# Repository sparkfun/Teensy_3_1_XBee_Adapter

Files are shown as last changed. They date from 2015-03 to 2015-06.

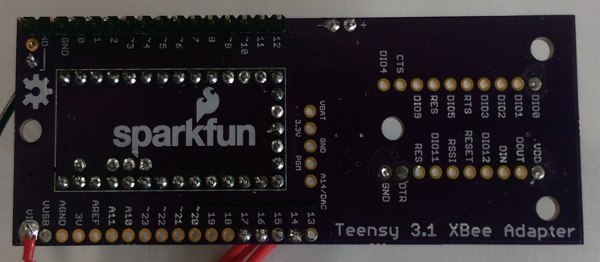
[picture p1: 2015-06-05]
Documentation/Bottom_board.jpg

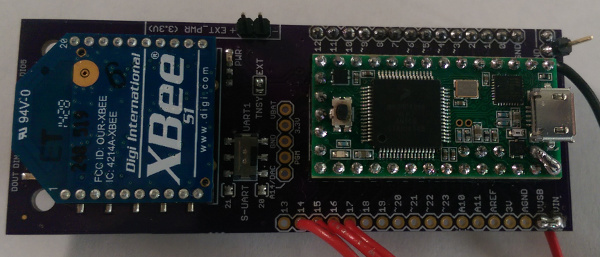
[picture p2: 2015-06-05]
Documentation/top_board.jpg

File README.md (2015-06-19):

SparkFun Teensy 3.1 XBee Adapter
=================================

SparkFun Teensy 3.1 XBee Adapter

[*SparkFun Teensy 3.1 XBee Adapter (BOB-13311)*](https://www.sparkfun.com/products/13311)

Adapter board from the Teensy3.1 to XBee radio modules.

Repository Contents
-------------------

* **/Documentation** - Datasheets, tutorial images. 
* **/Firmware** - Example code 
* **/Hardware** - Eagle design files (.brd, .sch)
* **/Production** - Production panel files (.brd)

Documentation
--------------
* **[Hookup Guide](https://learn.sparkfun.com/tutorials/teensy-xbee-adapter-hookup-guide)** - Basic hookup guide for the Teensy XBee Adapter.

License Information
-------------------
This product is _**open source**_! 

The **hardware** is released under [Creative Commons ShareAlike 4.0 International](https://creativecommons.org/licenses/by-sa/4.0/).
The firmware is released under the [MIT License](http://opensource.org/licenses/MIT). 

Please use, reuse, and modify these files as you see fit. Please maintain attribution to SparkFun Electronics and release anything derivative under the same license.

Distributed as-is; no warranty is given.

- Your friends at SparkFun.

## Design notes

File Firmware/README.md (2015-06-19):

SparkFun Teensy XBee Adapter Firmware
===================================

* **Examples** - Arduino examples

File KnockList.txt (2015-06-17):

Teensy 3.1 Xbee adapter knock list
	Mark (DONE) 

Identify Similar product repo (no lib, multiple examples)
	(DONE) -- User codebender for display and include github

Polish Examples folder
    (DONE)
	
Finish HookUp Guide text
	(Hookup guide link:
	https://learn.sparkfun.com/tutorials/teensy-xbee-adapter-hookup-guide)
	
	(DONE)Fix LED pins (should be f4-11)
	
Photograph with Juan
	(DONE)
	
Push to marcom

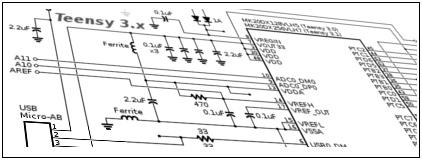
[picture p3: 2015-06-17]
Documentation/TeensySchematic.jpg

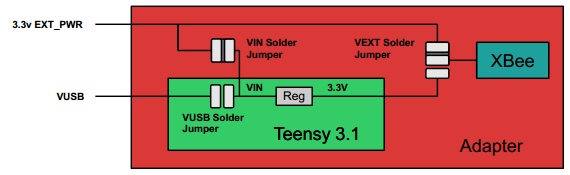
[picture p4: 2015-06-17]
Documentation/PowerOption2.png

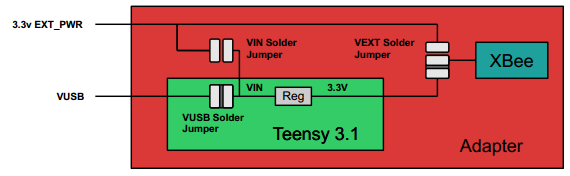
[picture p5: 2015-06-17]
Documentation/PowerOption1.png

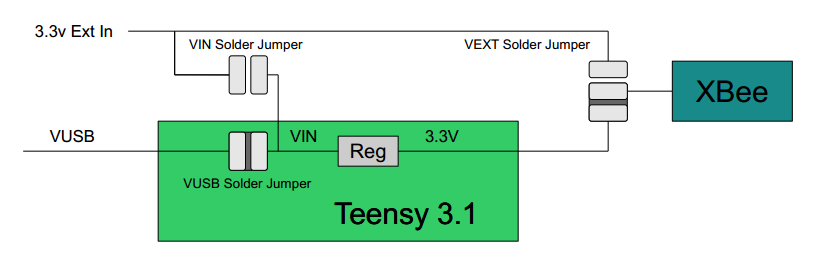
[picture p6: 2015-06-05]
Documentation/PO1.png

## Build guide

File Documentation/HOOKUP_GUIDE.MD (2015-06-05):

# Getting Started With The XBee And Teensy 3.1

## Introduction
When microcontroller power in a tight space is required, the Teensy 3.1/LC is a good place to get it.  When a decently ranged no-frills serial link is required, the XBee is the go-to.  The Teensy to XBee adapter board joins the two with easy, but how easy is it?  This tutorial will demonstrate the basics of using the adapter board.

This tutorial demonstrates:
* How to initialize Teensy 3.1/LC HW serial
* How to initialize Teensy 3.1 SW serial using softwareSerialAlt library
* The basics of packetizing data.
* How to make a simple controller that effects something far away
* How to build a wireless game controller for a computer.

### Materials Used

You will need a few components and tools to follow along with this tutorial. Here is what you will need:

-----------------------------------WISHLIST GOES HERE-----------------------------------

If you do not have specifically a 3.3V Arduino Pro, there are a number of ways to complete the walkthrough. In general, you will need:

* **Arduino or other microcontroller** -- You will need something that is capable of I<sup>2</sup>C and communicating back to the computer (e.g. [serial communications](tutorials/8)). The microcontroller needs to have a **3.3V I/O voltage** or you will have to use a level shifter. We are using the [3.3V Arduino Pro](https://www.sparkfun.com/products/10914), but the [3.3V Arduino Pro Mini](https://www.sparkfun.com/products/11114) would work as well.
* **Teensy 3.1/LC** -- If you are using a 5V Arduino, like the [Uno](https://www.sparkfun.com/products/11021) or [RedBoard](https://www.sparkfun.com/products/12757), you will need to use a level shifter, such as the [bi-directional logic level converter](https://www.sparkfun.com/products/12009).
* **Connectors** -- You will need to interface your microcontroller with the breakout board. [Male headers](https://www.sparkfun.com/products/116) are perfect if you're using a [breadboard](https://www.sparkfun.com/products/11026). Another option is to use [wire](https://www.sparkfun.com/products/11375) to connect the breakout board directly to the microcontroller.
* **Soldering tools** -- After you've picked a connector, you will need to solder it to the breakout board. A [simple soldering iron](https://www.sparkfun.com/products/9507) and some [solder](https://www.sparkfun.com/products/9163) should be all you need.

### Recommended Reading

Before getting started, there are a few concepts that you should be familiar with. If you haven't used a Teensy or XBee before, read these tutorials before continuing:

* [Teensy Quickstart](http://www.pjrc.com/teensy/first_use.html) - External link to PJRC, first powering of a Teensy
* [Teensyduino Software](http://www.pjrc.com/teensy/teensyduino.html) - External link to PJRC, using the Teensy with Arduino software
* [Exploring XBees and XCTU](https://learn.sparkfun.com/tutorials/exploring-xbees-and-xctu) - Guide to configuring the XBees using the XBee tool XCTU
* [XBee Buying Guide](https://www.sparkfun.com/pages/xbee_guide) - Shows various XBee models including current consumption
use an Arduino to control the APDS-9960
* [Serial Terminal Basics](https://learn.sparkfun.com/tutorials/terminal-basics) - Lots of information about serial.  If you've only ever used the Arduino Serial monitor (or no terminal at all), this is a good resource.  It shows how to get serial terminals working on Mac, Linux, and Windows.

### Tools or materials required

* Soldering iron and flux core solder
* Spare wire
* X-acto or knife for cutting traces (possibly)
* Breadboard

### Software required
* Arduino IDE
* Teensyduino add-on
* AltSoftSerial library
* X-CTU

## Hardware Overview
Look at this picture!  *look at it...*

## Assembly
The basic methodology for developing with the Teensy and XBee goes like this:
* Determine how to power
* Connect the hardware
* Configure the XBees
* Establish serial over XBee (test all systems)
* Build and test the actual project

### Determine how the system is going to be powered
The XBee requires around 3.3v to operate depending on model.  The Teensy has an on-board regulator that outputs 3.3v which is perfect, but only for lower power radios.

Photo

*Powering from the Teensy's internal regulator*

This is the default configuration.  The internal regulator can supply about 100mA of current for 3.3v use, including what is consumed by the Teensy and things on the 3.3v rail. XBees up to 2mW (non-"pro" models) consume up to 40mA, so if you have a basic XBee this is probably the route for you.  Supply 3.7 to 5.5v (or USB power) and you're good to go.

Photo

*Powering the XBee from an external 3.3v regulator*

If you have a higher powered XBee, or more than 100mA of load on your 3.3v rail, you'll need to disconnect the XBee from the internal regulator and supply 3.3v from somewhere else.  A [Breadboard Power Supply Stick](https://www.sparkfun.com/products/13157) is a possible power source for this application.

In this case, switch the TNSY-EXT jumper to EXT, short the VIN-EXT_PWR jumper, and cut the trace between the Teensy's USB PWR jumper.  Now both the Teensy and XBee are powered from the ext power pins, so you'll need to provide power and plug in the USB if you want to reprogramming the device.

### Now that powering has been figured out, it's time to connect the teensy to the XBee.
The XBee sockets straight into the adapter.  It's good to go!
Neither the Teensy nor the adapter has have headers.  Here are some options for connecting the two.
* Solder headers into the teensy, and pins into the adapter (or visa-versa) - This is a good option because the two are easily seperable.  Note: the pair are quite thick in this configuration and the headers are difficult to remove.  If you *know* you'll be moving to an alternate connection scheme, it may be a good idea to test things with short flexible wires before locking things down.
* Solder short lengths of wire between the pins you wish to connect - this is a good idea if you know you'll be moving to some more permenent solution.  Also, only solder wires where you need, such as power, ground, TX, RX, and miscelanious GPIO.
* Solder the two boards directly together without pins or wires at all - This is an advanced technique but results in a very thin board stack.  Don't do this until you are 100% confidant in your design!  Verify first, then solder together.  Seperating the boards afterwards can destroy them.

### Connect Periphery Equipment
Use the outer holes to connect all manor of switches and sensors that you wish to read from the Teensy.  This tutorial makes a controller, so buttons and knobs are connected as shown in this diagram.

*Fritzing diagram showing wiring of the buttons for this example*

### Configure the XBees
The XBees are shipped with a default configuration (see XBee documentation).  Even if they work out of the box, you'll be using the default IDs and will be suseptable to unseen XBees interfering with your system (because some other designer had the similar thought, "I'm the only one here, why not use the default IDs.") Also, you can change other more advanced features once you're familiar with the concepts.

**The parameters used for this demo**
* ID/PAN ID = A5F1 - This can be any 16 bit hex value used to identify your network.  Make sure it is the same for both radios and unique in your area.  A5F1 was randomly chosen for this guide.  You can choose any ID for your network.
* Data rate = 9600
* Parity = N
* All others at factory default

**Configuring XBees with USB based explorers**

* Socket an XBee into the explorer matching the silkscreen orientation
* Plug the explorer into the USB port
* Open X-CTU
* Select your explorer's serial port
* Querry the XBee to make sure the drivers are working
* Read the configuration from the XBee
* Modify the parameters
* Write the new configuration to the XBee

Repeat this process so that both XBees have the new configuration.

### Power the System!
Apply (HOW MUCH VOLTAG?) to the system.  Does the (WHAT TURNS ON?)  Try running the blink sketch to determine if the Teensy is really powered and ready to recieve firmware.

## Firmware
### Theory
### Working with your serial ports
Difficulties arise while working with wireless devices because more than one serial port is in use.  Where Arduino allows you to simply load the serial monitor to talk to your code, be extra careful remembering which ports what device and which terminal are using.

For this example the computer is one party in the communication by using the XBee explorer.  Get this port open and communicating to the XBee explorer, then leave it alone.  It ushers bytes you type into it into the air, and prints whatever comes into it's antenna to your screen.  When the system is fully functional, this terminal will tell you what buttons are being pressed.

The Arduino serial monitor connects to the target over the USB cable.  This serial link isn't going to the XBee and won't be connected to anything when the controller is fully mobile, so may not have much use but it's important to remember that it exists, and to not confuse it with the other serial ports.  Actually, it can be usefull to get debugging information from your program while working with it.

The trickest serial link in this project is the one that goes from the Teensy to the XBee because we have little information about it.  If you have access to an oscilliscope the link can be probed, but in lieu of that all we get is a little blinking light we become thankful for.

### Test your serial and XBee configuration
*Two sketches are provided to ease bringing the XBees online.  They pass data between the XBee and the serial monitor using the HW UART or the SW UART 'AltSoftSerial'*

**teensy_3_1_xbee_UART1_example**

Set the adapter's serial switch to UART1.  Then, load and run the example.  Open the serial monitor.  Text entered in the serial monitor will be passed to the XBee, and come out the X-CTU (or other, I use Tera Term) serial monitor.  Typing in that terminal will send the text back to the Arduino serial monitor.  This tests the HW UART and XBee configurations

**teensy_3_1_xbee_SUART_example**

This sketch works much like the UART1 example but with the AltSoftSerial library, leaving the HW UART free to connect to other resources.  Set the adapter's switch to UART1 and run the sketch.  Text should be passed between the two serial terminals.

### Running the demo sketches

**teensy_3_1_xbee_buttons_and_leds_example**

This sketch demonstrates bi-directional communication and shows off operation that is more than just data echo.

**Connections**

* Attach buttons to pins 14-17 of the Teensy, and to ground.  The pins are pulled up inside the teensy and will float high until a button is depressed.
* Attach LEDs from pins 14-21 of the Teensy, through a current limiting resistor, to ground.  It's not so important to have all 8, 2 or 3 is enough to demonstrate the effect.

**Each time the loop() runs, the sketch**

* Converts button presses to an ascii repersentation
* Prints the button states to the Arduino serial monitor
* Transmits the button states as a series of ascii characters
* Checks for received data from the XBee.  If a number 1-8 is received, the associated LED on pins 14-21 is illuminated.  If any other character is received, all 8 LEDs are are switched off.

**teensy_3_1_xbee_gamepad_controller**

This sketch is used to create a NES style 8 button controller with D-pad, A, B, Start and Select.  It works similarly to the previous example in that it builds a packet of ascii characters that depict the state of the button and transmits them out the XBee.  It has an upgraded.  It's different in that the LED feedback and Arduino serial manager code has been removed, and button state information is now tracked.  This sketch checks the button states as fast as possible, and only sends an ascii packet out the XBee if the state of the buttons has changed.  This allows the XBee to not consume superflurious power if the controller is on battery power.

**Connections**

* Pin 2: Start button
* Pin 3: Select button
* Pin 4: B button
* Pin 5: A button
* Pin 6: Up button
* Pin 7: Down button
* Pin 8: Left button
* Pin 9: Right button
* Set switch to UART1

**teensy_3_1_xbee_gamepad_receiver**

This sketch causes the Teensy to behave like a USB keyboard.  It parses the data from the XBee and 'presses a key' in corrispondence with what key is being depressed on the controller.  When a controller button is pressed and held, the teensy acts like a keyboard with a key held down.  This allows the teensy to interface to a ROM emulator or game that has map-able keyboard input.

**Configuration**

* Set switch to UART1
* In the Arduino IDE, Select Tools -> USB type: -> Keyboard + Mouse + Joystick

After the sketch uploads your computer may have to go through a new device like detection.  When it is done, open a text editor and use the controller to send some XBee data to the receiver.  If everything is correct, numbers should be typed into the text editor.

This sketch was tested on windows 7 and mac OS 10.10.

## Conclusion

## Resources and Going Further

Going Further/Further Reading

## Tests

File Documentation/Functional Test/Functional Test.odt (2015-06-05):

# Functional Test

## Hardware uart test

### Method

Run the Hardware Uart test from the github repository

Use Teensy 3.1 and Teensy LC

### Results

Sketch runs and passes data on Teensy 3.1

Sketch runs and passes data on Teensy LC

Switch label is correct.

## Software uart test

### Method

Run the Software UART test from the github repository

Use Teensy 3.1 and Teensy LC

### Results

Sketch runs and passes data on 3.1.

Switch label is correct.

Teensy LC does not work- perhaps AltSoftwareSerial needs to be updated

## Low power configuration


### Method

1. M ake the jumper configuration as shown.
2. Attach to computer USB port.
3. Replace the XBee with a series of loads 0mA to 500mA
4. Measure VIN on the Teensy, regulated 3.3v rail, and current load applied

### Results

The internal regulator starts cutting out above 200mA and the voltage quickly drops. Damage not apparent.

## High power configuration

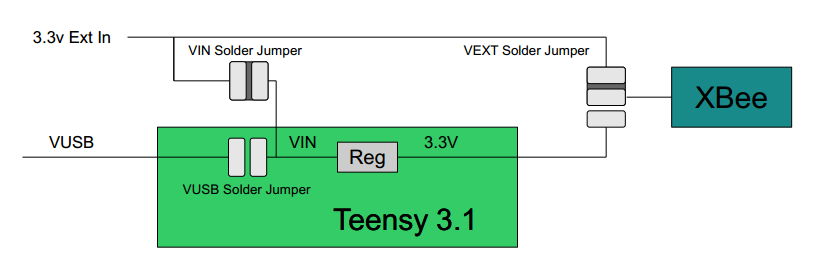
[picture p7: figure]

### Method

1. M ake the jumper configuration as shown.
2. Attack to 3.3v stable regulated supply.
3. Replace the XBee with a series of loads 0mA to 500mA
4. Measure VIN on the Teensy, regulated 3.3v rail, and current load applied

### Results

The connection is direct, so the slight current/voltage relationship is due to the source and wire impedance. Notice that at this level, there is no 5v rail.

## LED colors and operations

### Method

1. Run the HW UART code. This will test will test DIO5, DOUT and DIN. Send data from the USB dongle to the Teensy via airwaves to test the signal strength LED.
2. Do the colors match other XBee products?

Function | Arduino shield | USB dongle
RSSI | Green | Green
Air to MCU | "DOUT", Red | "TX", Red
MCU to Air | "DIN", Green | "RX", Green
DIO5 | Green | Not Present
PWR | Red | Red

3. Are you blinded by the lights?

### Results

Function | Silk/Color | Correct? | Brightness OK?
RSSI | Green | Yes | Yes
Air to Teensy | "DIN", Red | Color correct, lable not | Yes
Teensy to Air | "DOUT", Green | Color correct, lable not | Yes
DIO5 | Green | Yes | Yes
PWR | Red | Yes | Yes

## Action items/Corrections

1. Twist power LEDs to match other LEDs.
2. Mark PWR to LED and jumper pads.
3. Swap DIN and DOUT lables.
4. Add top flame
5. Remove AGND DGND jumper
6. Fix dimention lines- make them go all the way to the holes
7. Do something about Teensy LC and software serial?
8. Update revision number

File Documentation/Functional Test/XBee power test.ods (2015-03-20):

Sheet: Low Power
Load I (amps) | Vin (volts) | 3.3v(volts) | Resistor calcs
0.000 | 4.980 | 3.260 | Voltage | Amperage | Ohms | Real resistor | Amperage
0.055 | 4.880 | 3.240 | 3.3 | 0.05 | 66 | 60 | 0.06
0.081 | 4.830 | 3.240 | 3.3 | 0.1 | 33 | 40 | 0.08
0.109 | 4.780 | 3.230 | 3.3 | 0.15 | 22 | 30 | 0.11
0.214 | 4.590 | 3.210 | 3.3 | 0.2 | 16.5 | 14.7 | 0.22
0.233 | 4.550 | 2.330 | 3.3 | 0.25 | 13.2 | 10 | 0.33
0.234 | 4.550 | 2.110 | 3.3 | 0.3 | 11 | 9 | 0.37
0.238 | 4.550 | 1.780 | 3.3 | 0.35 | 9.43 | 6.5 | 0.51
 |  |  | 3.3 | 0.4 | 8.25
 |  |  | 3.3 | 0.45 | 7.33
 |  |  | 3.3 | 0.5 | 6.6
 |  |  | 3.3 | 0.55 | 6
 |  |  | 3.3 | 0.6 | 5.5
 |  |  | 3.3 | 0.65 | 5.08
 |  |  | 3.3 | 0.7 | 4.71
 |  |  | 3.3 | 0.75 | 4.4
 |  |  | 3.3 | 0.8 | 4.13
 |  |  | 3.3 | 0.85 | 3.88
 |  |  | 3.3 | 0.9 | 3.67
 |  |  | 3.3 | 0.95 | 3.47
 |  |  | 3.3 | 1 | 3.3

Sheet: Sheet2
Load I (amps) | (same) | 3.3v(volts)
0.000 |  | 3.310
0.056 |  | 3.300
0.083 |  | 3.295
0.110 |  | 3.285
0.217 |  | 3.256
0.330 |  | 3.225
0.354 |  | 3.218
0.417 |  | 3.201
0.512 |  | 3.174

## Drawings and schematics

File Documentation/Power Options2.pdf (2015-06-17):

# XBee

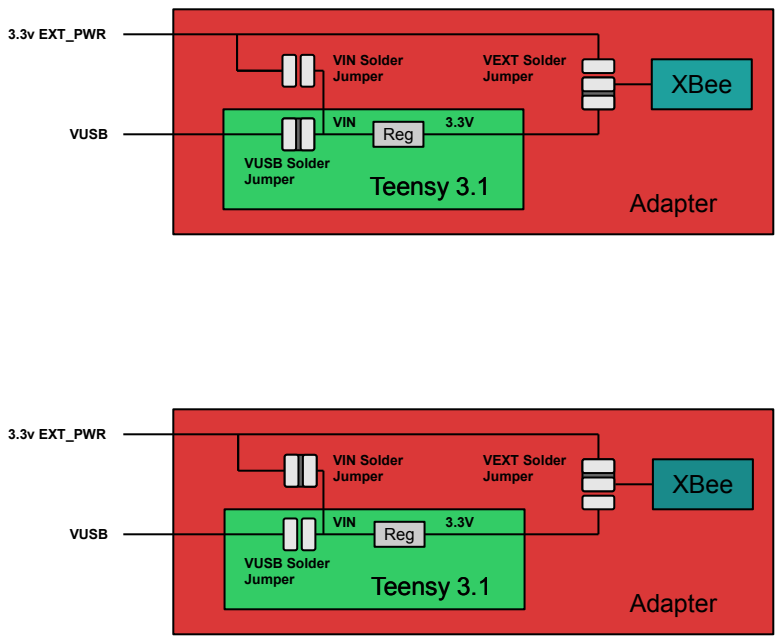
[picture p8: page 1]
Reg; VIN; VUSB; Teensy 3.1; 3.3v EXT_PWR; VUSB Solder Jumper; VIN Solder Jumper; VEXT Solder Jumper; XBee; Adapter

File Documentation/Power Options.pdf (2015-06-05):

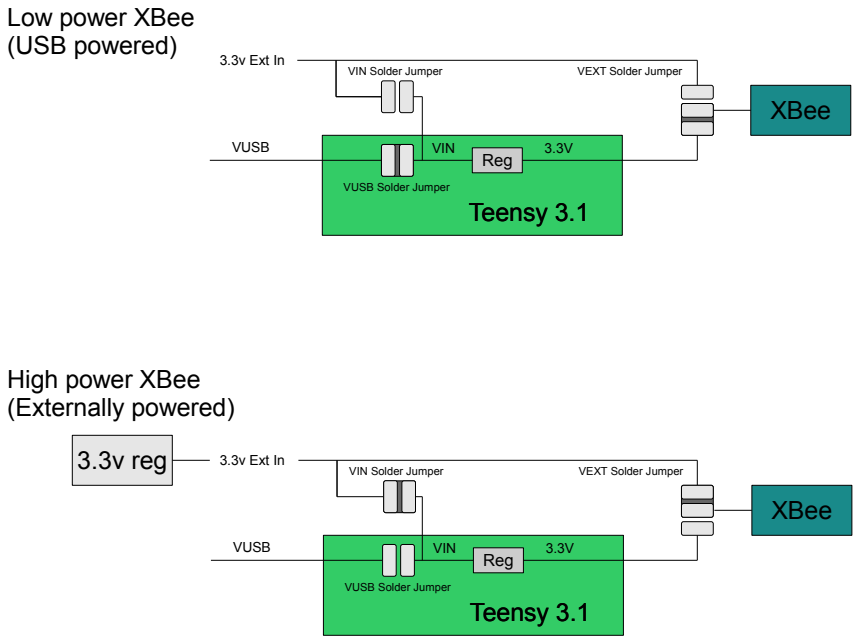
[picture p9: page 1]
XBee; Reg; VUSB; VIN; 3.3v reg; Teensy 3.1; 3.3v Ext In; VIN Solder Jumper; VEXT Solder Jumper

Low power XBee
(USB powered)

VUSB Solder Jumper

High power XBee
(Externally powered)

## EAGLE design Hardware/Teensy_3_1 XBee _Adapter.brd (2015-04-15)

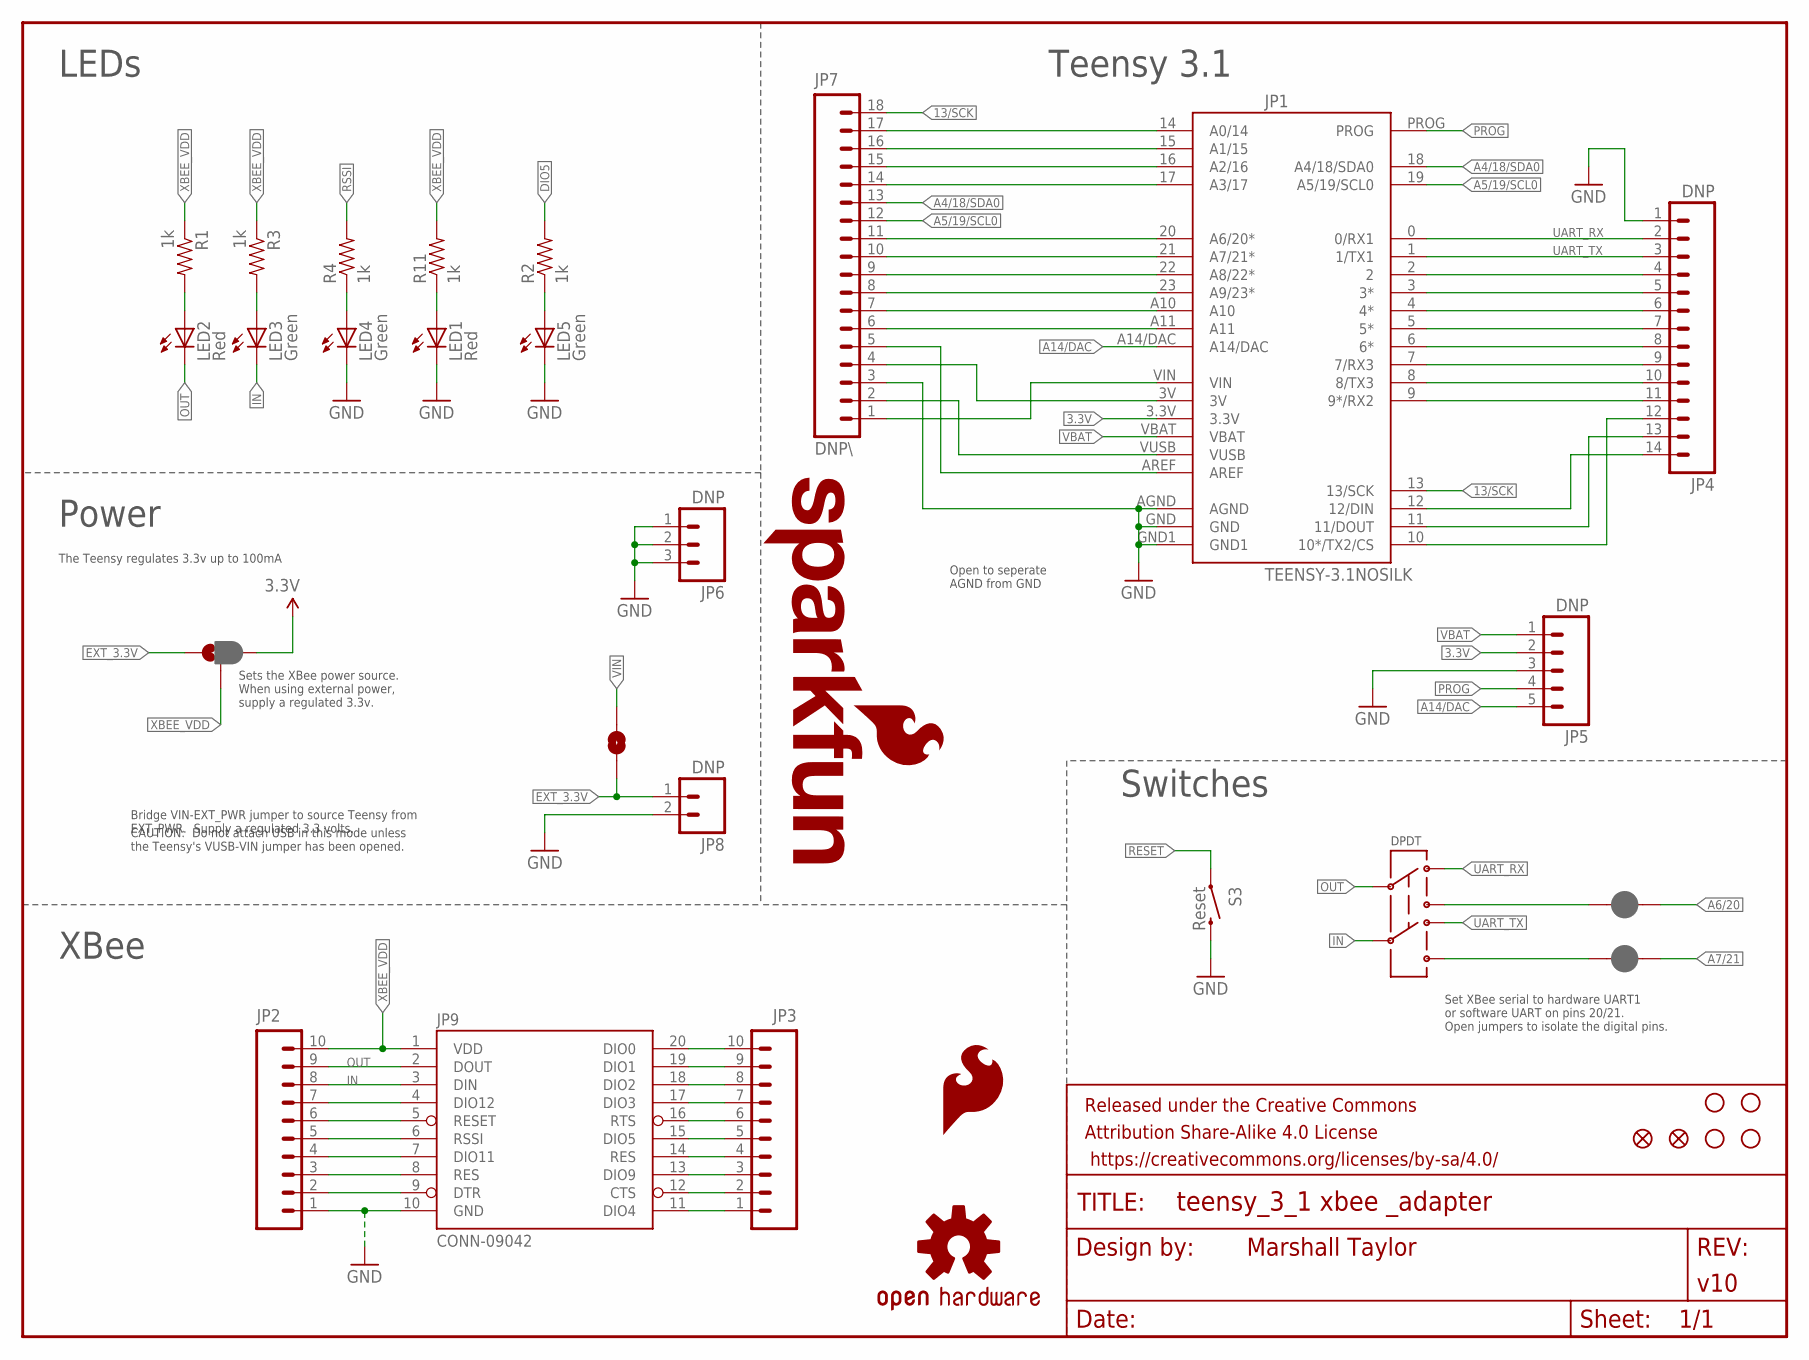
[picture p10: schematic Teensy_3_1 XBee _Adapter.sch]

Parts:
FID1, FID2: FIDUCIAL1X2; FIDUCIAL-1X2
FRAME1: FRAME-LETTER; CREATIVE_COMMONS
JP1: TEENSY-3.1NOSILK; TEENSY-3.1_NOSILK
JP2, JP3: M10NO_SILK_PTH_FEMALE; 1X10_NO_SILK
JP4: DNP; 1X14
JP5: DNP; 1X05
JP6: DNP; 1X03
JP7: DNP\; 1X18
JP8: DNP; 1X02
JP9: CONN-09042; XBEE-SMD
LED1, LED2: Red; LED-0603
LED3, LED4, LED5: Green; LED-0603
LOGO1: SFE_LOGO_FLAME.2_INCH; SFE_LOGO_FLAME_.2
LOGO2: OSHW-LOGOM; OSHW-LOGO-M
LOGO3: SFE_LOGO_NAME_FLAME.2_INCH; SFE_LOGO_NAME_FLAME_.2
R1, R2, R3, R4, R11: 1k; 0603-RES
S2: DPDT; AYZ0202
S3: Reset; TACTILE-SWITCH-SMD
SJ1: D_TX; PAD-JUMPER-2-NC_BY_PASTE_YES_SILK
SJ3: D_RX; PAD-JUMPER-2-NC_BY_PASTE_YES_SILK
SJ4: JUMPER-PAD-3-2OF3_NC_BY_PASTE; PAD-JUMPER-3-2OF3_NC_BY_PASTE_YES_SILK_FULL_BOX
SJ5: EXT_JPR; PAD-JUMPER-2-NO_YES_SILK
STANDOFF1, STANDOFF2, STANDOFF3, STANDOFF4: STAND-OFF

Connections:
2: JP1.2, JP4.4
3: JP1.3 (3*), JP4.5
3.3V: JP1.3.3V, JP5.2, SJ4.3
3V: JP1.3V, JP7.4
4: JP1.4 (4*), JP4.6
5: JP1.5 (5*), JP4.7
6: JP1.6 (6*), JP4.8
7/RX3: JP1.7 (7/RX3), JP4.9
8/TX3: JP1.8 (8/TX3), JP4.10
9/RX2: JP1.9 (9*/RX2), JP4.11
10/TX2/CS: JP1.10 (10*/TX2/CS), JP4.12
11/DOUT: JP1.11 (11/DOUT), JP4.13
12/DIN: JP1.12 (12/DIN), JP4.14
13/SCK: JP1.13 (13/SCK), JP7.18
A0/14: JP1.14 (A0/14), JP7.17
A1/15: JP1.15 (A1/15), JP7.16
A2/16: JP1.16 (A2/16), JP7.15
A3/17: JP1.17 (A3/17), JP7.14
A4/18/SDA0: JP1.18 (A4/18/SDA0), JP7.13
A5/19/SCL0: JP1.19 (A5/19/SCL0), JP7.12
A6/20: JP1.20 (A6/20*), JP7.11, SJ3.1
A7/21: JP1.21 (A7/21*), JP7.10, SJ1.1
A8/22: JP1.22 (A8/22*), JP7.9
A9/23: JP1.23 (A9/23*), JP7.8
A10: JP1.A10, JP7.7
A11: JP1.A11, JP7.6
A14/DAC: JP1.A14/DAC, JP5.5
AREF: JP1.AREF, JP7.5
CTS: JP3.2, JP9.12 (CTS)
DIO0: JP3.10, JP9.20 (DIO0)
DIO1: JP3.9, JP9.19 (DIO1)
DIO2: JP3.8, JP9.18 (DIO2)
DIO3: JP3.7, JP9.17 (DIO3)
DIO4: JP3.1, JP9.11 (DIO4)
DIO5: JP3.5, JP9.15 (DIO5), R2.2
DIO9: JP3.3, JP9.13 (DIO9)
DIO11: JP2.4, JP9.7 (DIO11)
DIO12: JP2.7, JP9.4 (DIO12)
DTR: JP2.2, JP9.9 (DTR)
EXT_3.3V: JP8.1, SJ4.1, SJ5.2
GND: JP1.AGND, JP1.GND, JP1.GND1, JP2.1, JP4.1, JP5.3, JP6.1, JP6.2, JP6.3, JP7.3, JP8.2, JP9.10 (GND), LED1.C, LED4.C, LED5.C, S3.3 (2)
IN: JP2.8, JP9.3 (DIN), LED3.C, S2.5
unnamed: LED1.A, R11.1
unnamed: LED2.A, R1.2
unnamed: LED3.A, R3.2
unnamed: LED4.A, R4.1
unnamed: LED5.A, R2.1
unnamed: S2.6, SJ1.2
unnamed: S2.3, SJ3.2
OUT: JP2.9, JP9.2 (DOUT), LED2.C, S2.2
PROG: JP1.PROG, JP5.4
RES: JP2.3, JP9.8 (RES)
RES2: JP3.4, JP9.14 (RES)
RESET: JP2.6, JP9.5 (RESET), S3.1
RSSI: JP2.5, JP9.6 (RSSI), R4.2
RTS: JP3.6, JP9.16 (RTS)
UART_RX: JP1.0 (0/RX1), JP4.2, S2.1
UART_TX: JP1.1 (1/TX1), JP4.3, S2.4
VBAT: JP1.VBAT, JP5.1
VIN: JP1.VIN, JP7.1, SJ5.1
VUSB: JP1.VUSB, JP7.2
XBEE_VDD: JP2.10, JP9.1 (VDD), R1.1, R3.1, R11.2, SJ4.2

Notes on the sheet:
Switches
Teensy 3.1
XBee
Power
LEDs
The Teensy regulates 3.3v up to 100mA
Sets the XBee power source. When using external power, supply a regulated 3.3v.
Bridge VIN-EXT_PWR jumper to source Teensy from EXT_PWR. Supply a regulated 3.3 volts.
CAUTION: Do not attach USB in this mode unless the Teensy's VUSB-VIN jumper has been opened.
Set XBee serial to hardware UART1 or software UART on pins 20/21. Open jumpers to isolate the digital pins.
DPDT
Open to seperate AGND from GND

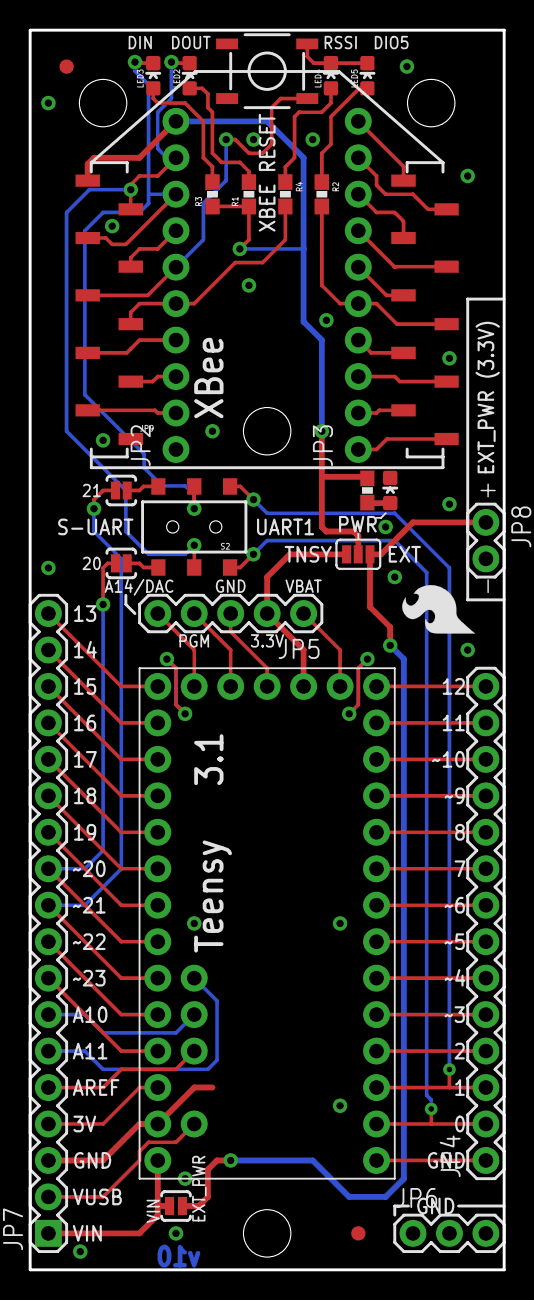
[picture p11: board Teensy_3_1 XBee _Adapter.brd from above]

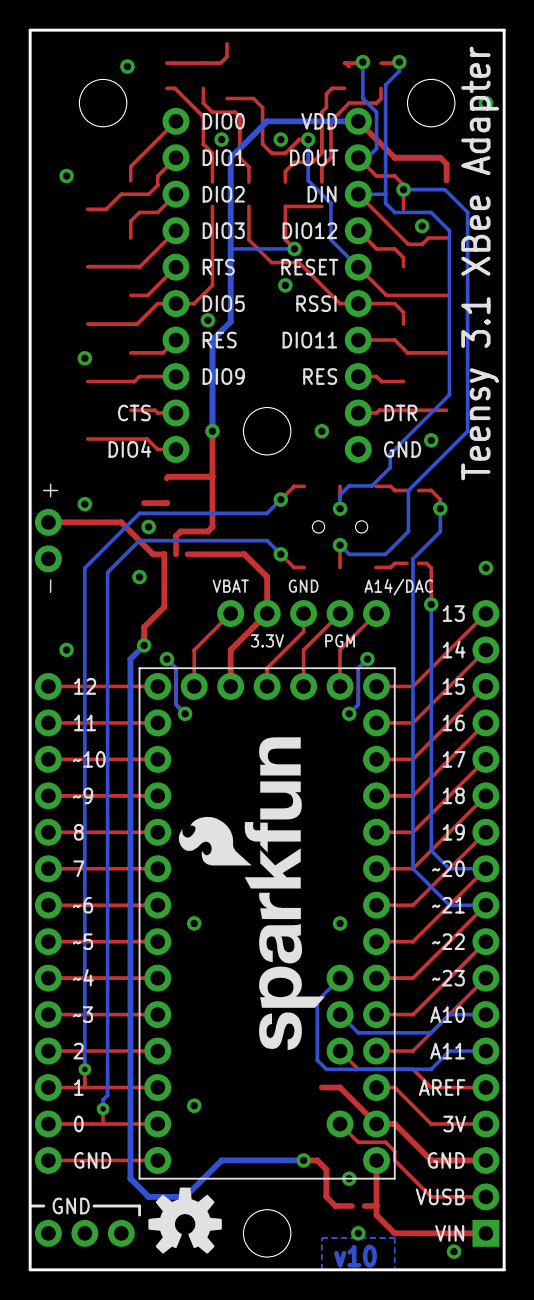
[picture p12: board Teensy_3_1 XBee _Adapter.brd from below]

Board: 2 copper layers, 33.0 x 86.4 mm, 35 parts (2 on the bottom side), 62 nets.

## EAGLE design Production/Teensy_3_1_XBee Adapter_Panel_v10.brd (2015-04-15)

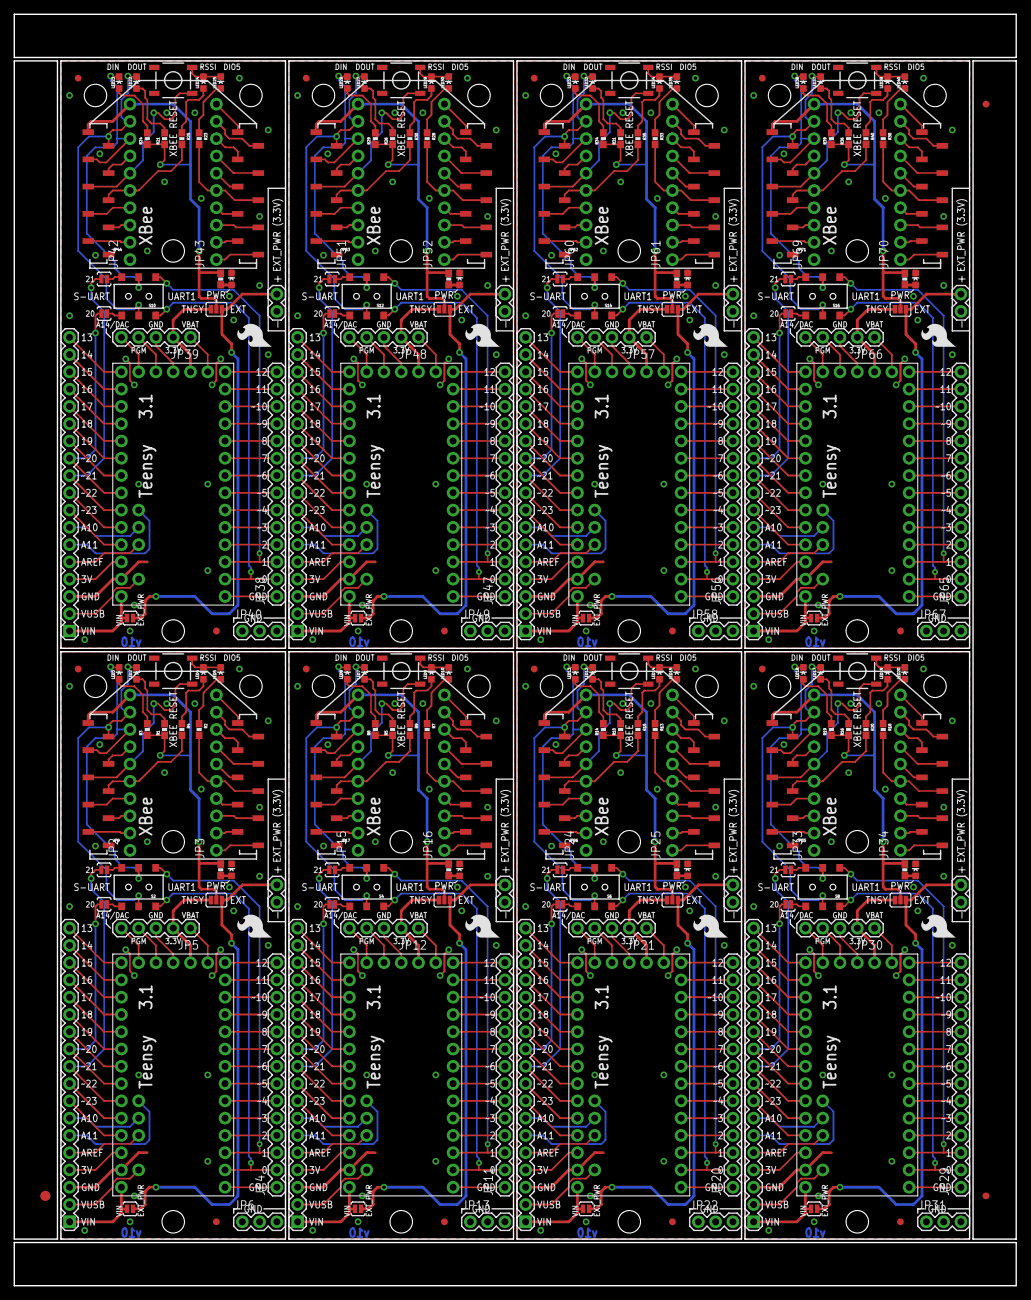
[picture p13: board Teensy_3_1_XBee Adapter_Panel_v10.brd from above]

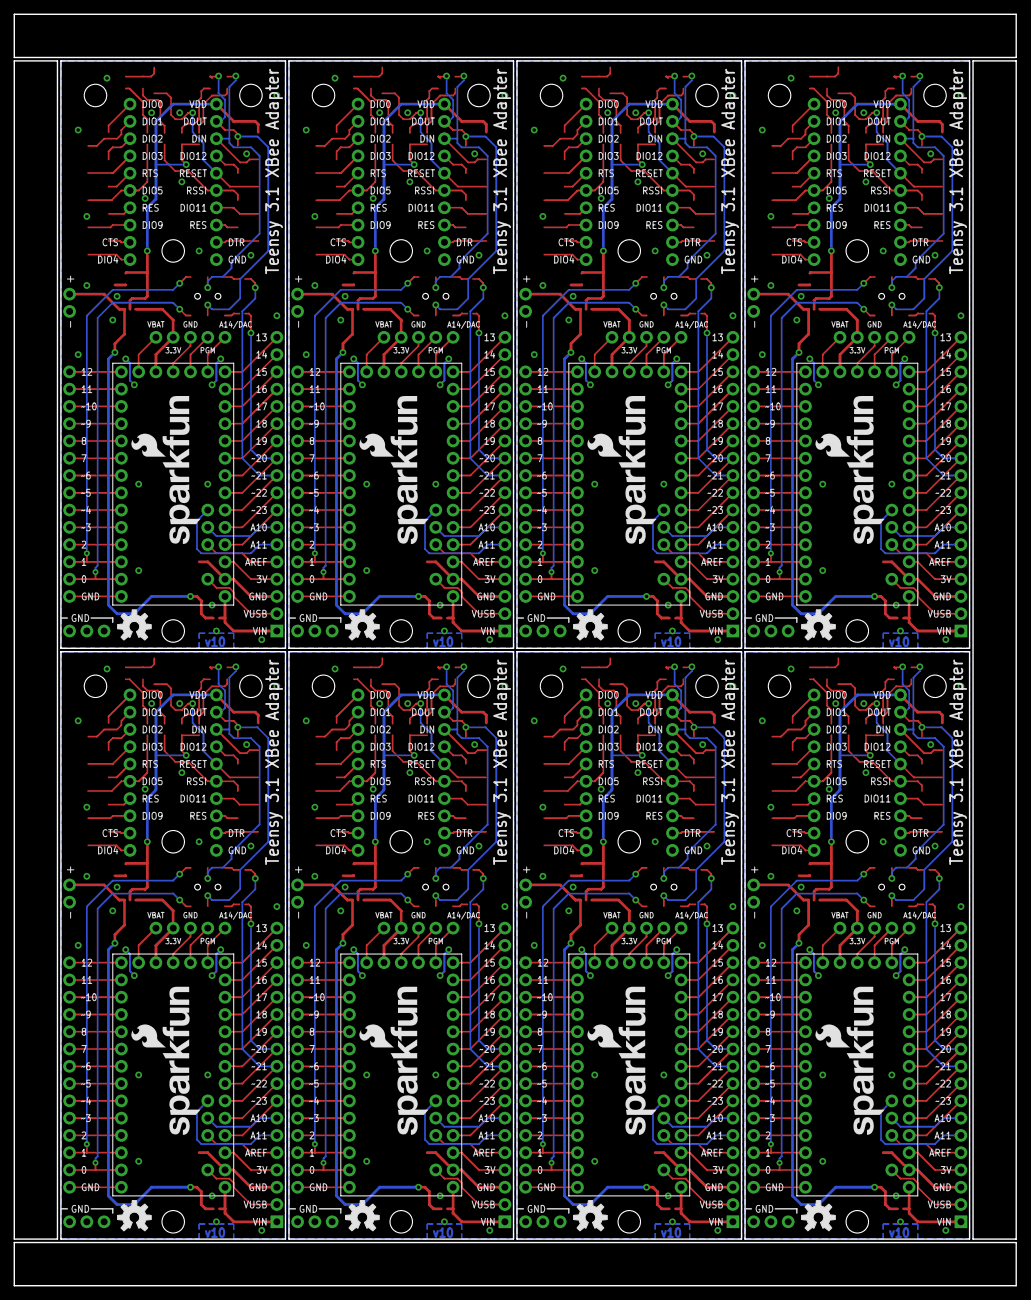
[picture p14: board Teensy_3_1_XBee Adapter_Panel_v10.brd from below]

Board: 2 copper layers, 147.3 x 186.9 mm, 275 parts (16 on the bottom side), 496 nets.

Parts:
E$1: FIDUCIAL-1.5X3
E$4, E$5: FIDUCIAL-1X2
FID1, FID2, FID3, FID4, FID5, FID6, FID7, FID8, FID9, FID10, FID11, FID12, FID13, FID14, FID15, FID16: FIDUCIAL1X2; FIDUCIAL-1X2
JP1, JP10, JP19, JP28, JP37, JP46, JP55, JP64: TEENSY-3.1NOSILK; TEENSY-3.1_NOSILK
JP2, JP3, JP15, JP16, JP24, JP25, JP33, JP34, JP42, JP43, JP51, JP52, JP60, JP61, JP69, JP70: 1X10_NO_SILK
JP4, JP11, JP20, JP29, JP38, JP47, JP56, JP65: DNP; 1X14
JP5, JP12, JP21, JP30, JP39, JP48, JP57, JP66: DNP; 1X05
JP6, JP13, JP22, JP31, JP40, JP49, JP58, JP67: DNP; 1X03
JP7, JP14, JP23, JP32, JP41, JP50, JP59, JP68: DNP\; 1X18
JP8, JP18, JP27, JP36, JP45, JP54, JP63, JP72: DNP; 1X02
JP9, JP17, JP26, JP35, JP44, JP53, JP62, JP71: CONN-09042; XBEE-SMD
LED1, LED2, LED6, LED7, LED11, LED12, LED16, LED17, LED21, LED22, LED26, LED27, LED31, LED32, LED36, LED37: Red; LED-0603
LED3, LED4, LED5, LED8, LED9, LED10, LED13, LED14, LED15, LED18, LED19, LED20, LED23, LED24, LED25, LED28, LED29, LED30, LED33, LED34, LED35, LED38, LED39, LED40: Green; LED-0603
LOGO1, LOGO6, LOGO9, LOGO12, LOGO15, LOGO18, LOGO21, LOGO24: SFE_LOGO_FLAME.2_INCH; SFE_LOGO_FLAME_.2
LOGO2, LOGO4, LOGO7, LOGO10, LOGO13, LOGO16, LOGO19, LOGO22: OSHW-LOGOM; OSHW-LOGO-M
LOGO3, LOGO5, LOGO8, LOGO11, LOGO14, LOGO17, LOGO20, LOGO23: SFE_LOGO_NAME_FLAME.2_INCH; SFE_LOGO_NAME_FLAME_.2
R1, R2, R3, R4, R5, R6, R7, R8, R9, R10, R11, R12, R13, R14, R15, R16, R17, R18, R19, R20, R21, R22, R23, R24, R25, R26, R27, R28, R29, R30, R31, R32, R33, R34, R35, R36, R37, R38, R39, R40: 1k; 0603-RES
S1, S3, S5, S7, S9, S11, S13, S15: Reset; TACTILE-SWITCH-SMD
S2, S4, S6, S8, S10, S12, S14, S16: DPDT; AYZ0202
SJ1, SJ2, SJ9, SJ13, SJ17, SJ21, SJ25, SJ29: D_TX; PAD-JUMPER-2-NC_BY_PASTE_YES_SILK
SJ3, SJ6, SJ10, SJ14, SJ18, SJ22, SJ26, SJ30: D_RX; PAD-JUMPER-2-NC_BY_PASTE_YES_SILK
SJ4, SJ7, SJ11, SJ15, SJ19, SJ23, SJ27, SJ31: JUMPER-PAD-3-2OF3_NC_BY_PASTE; PAD-JUMPER-3-2OF3_NC_BY_PASTE_YES_SILK_FULL_BOX
SJ5, SJ8, SJ12, SJ16, SJ20, SJ24, SJ28, SJ32: EXT_JPR; PAD-JUMPER-2-NO_YES_SILK
STANDOFF1, STANDOFF2, STANDOFF3, STANDOFF4, STANDOFF5, STANDOFF6, STANDOFF7, STANDOFF8, STANDOFF9, STANDOFF10, STANDOFF11, STANDOFF12, STANDOFF13, STANDOFF14, STANDOFF15, STANDOFF16, STANDOFF17, STANDOFF18, STANDOFF19, STANDOFF20, STANDOFF21, STANDOFF22, STANDOFF23, STANDOFF24, STANDOFF25, STANDOFF26, STANDOFF27, STANDOFF28, STANDOFF29, STANDOFF30, STANDOFF31, STANDOFF32: STAND-OFF

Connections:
1: JP10.2, JP11.4
2: JP1.2, JP4.4
3: JP1.3, JP4.5
3.3V: JP1.3.3V, JP5.2, SJ4.3
3.3V1: JP10.3.3V, JP12.2, SJ7.3
3.3V2: JP19.3.3V, JP21.2, SJ11.3
3.3V3: JP28.3.3V, JP30.2, SJ15.3
3.3V4: JP37.3.3V, JP39.2, SJ19.3
3.3V5: JP46.3.3V, JP48.2, SJ23.3
3.3V6: JP55.3.3V, JP57.2, SJ27.3
3.3V7: JP64.3.3V, JP66.2, SJ31.3
3V: JP1.3V, JP7.4
3V1: JP10.3V, JP14.4
3V2: JP19.3V, JP23.4
3V3: JP28.3V, JP32.4
3V4: JP37.3V, JP41.4
3V5: JP46.3V, JP50.4
3V6: JP55.3V, JP59.4
3V7: JP64.3V, JP68.4
4: JP1.4, JP4.6
5: JP1.5, JP4.7
6: JP1.6, JP4.8
7: JP10.4, JP11.6
7/RX1: JP10.7, JP11.9
7/RX2: JP19.7, JP20.9
7/RX3: JP1.7, JP4.9
7/RX4: JP28.7, JP29.9
7/RX5: JP37.7, JP38.9
7/RX6: JP46.7, JP47.9
7/RX7: JP55.7, JP56.9
7/RX8: JP64.7, JP65.9
8: JP10.5, JP11.7
8/TX1: JP10.8, JP11.10
8/TX2: JP19.8, JP20.10
8/TX3: JP1.8, JP4.10
8/TX4: JP28.8, JP29.10
8/TX5: JP37.8, JP38.10
8/TX6: JP46.8, JP47.10
8/TX7: JP55.8, JP56.10
8/TX8: JP64.8, JP65.10
9: JP10.6, JP11.8
9/RX1: JP10.9, JP11.11
9/RX2: JP1.9, JP4.11
9/RX3: JP19.9, JP20.11
9/RX4: JP28.9, JP29.11
9/RX5: JP37.9, JP38.11
9/RX6: JP46.9, JP47.11
9/RX7: JP55.9, JP56.11
9/RX8: JP64.9, JP65.11
10: JP10.3, JP11.5
10/TX2/CS: JP1.10, JP4.12
10/TX2/CS1: JP10.10, JP11.12
10/TX2/CS2: JP19.10, JP20.12
10/TX2/CS3: JP28.10, JP29.12
10/TX2/CS4: JP37.10, JP38.12
10/TX2/CS5: JP46.10, JP47.12
10/TX2/CS6: JP55.10, JP56.12
10/TX2/CS7: JP64.10, JP65.12
11: JP19.2, JP20.4
11/DOUT: JP1.11, JP4.13
11/DOUT1: JP10.11, JP11.13
11/DOUT2: JP19.11, JP20.13
11/DOUT3: JP28.11, JP29.13
11/DOUT4: JP37.11, JP38.13
11/DOUT5: JP46.11, JP47.13
11/DOUT6: JP55.11, JP56.13
11/DOUT7: JP64.11, JP65.13
12: JP19.4, JP20.6
12/DIN: JP1.12, JP4.14
12/DIN1: JP10.12, JP11.14
12/DIN2: JP19.12, JP20.14
12/DIN3: JP28.12, JP29.14
12/DIN4: JP37.12, JP38.14
12/DIN5: JP46.12, JP47.14
12/DIN6: JP55.12, JP56.14
12/DIN7: JP64.12, JP65.14
13: JP19.5, JP20.7
13/SCK: JP1.13, JP7.18
13/SCK1: JP10.13, JP14.18
13/SCK2: JP19.13, JP23.18
13/SCK3: JP28.13, JP32.18
13/SCK4: JP37.13, JP41.18
13/SCK5: JP46.13, JP50.18
13/SCK6: JP55.13, JP59.18
13/SCK7: JP64.13, JP68.18
14: JP19.6, JP20.8
15: JP19.3, JP20.5
16: JP28.2, JP29.4
17: JP28.4, JP29.6
18: JP28.5, JP29.7
19: JP28.6, JP29.8
20: JP28.3, JP29.5
21: JP37.2, JP38.4
22: JP37.4, JP38.6
23: JP37.5, JP38.7
24: JP37.6, JP38.8
25: JP37.3, JP38.5
26: JP46.2, JP47.4
27: JP46.4, JP47.6
28: JP46.5, JP47.7
29: JP46.6, JP47.8
30: JP46.3, JP47.5
31: JP55.2, JP56.4
32: JP55.4, JP56.6
33: JP55.5, JP56.7
34: JP55.6, JP56.8
35: JP55.3, JP56.5
36: JP64.2, JP65.4
37: JP64.4, JP65.6
38: JP64.5, JP65.7
39: JP64.6, JP65.8
40: JP64.3, JP65.5
A0/1: JP10.14, JP14.17
A0/2: JP19.14, JP23.17
A0/3: JP28.14, JP32.17
A0/4: JP37.14, JP41.17
A0/5: JP46.14, JP50.17
A0/6: JP55.14, JP59.17
A0/7: JP64.14, JP68.17
A0/14: JP1.14, JP7.17
A1: JP10.A10, JP14.7
A1/1: JP10.15, JP14.16
A1/2: JP19.15, JP23.16
A1/3: JP28.15, JP32.16
A1/4: JP37.15, JP41.16
A1/5: JP46.15, JP50.16
A1/6: JP55.15, JP59.16
A1/7: JP64.15, JP68.16
A1/15: JP1.15, JP7.16
A2: JP10.A11, JP14.6
A2/1: JP10.16, JP14.15
A2/2: JP19.16, JP23.15
A2/3: JP28.16, JP32.15
A2/4: JP37.16, JP41.15
A2/5: JP46.16, JP50.15
A2/6: JP55.16, JP59.15
A2/7: JP64.16, JP68.15
A2/16: JP1.16, JP7.15
A3: JP19.A10, JP23.7
A3/1: JP10.17, JP14.14
A3/2: JP19.17, JP23.14
A3/3: JP28.17, JP32.14
A3/4: JP37.17, JP41.14
A3/5: JP46.17, JP50.14
A3/6: JP55.17, JP59.14
A3/7: JP64.17, JP68.14
A3/17: JP1.17, JP7.14
A4: JP19.A11, JP23.6
A4/18/SDA0: JP1.18, JP7.13
A4/18/SDA1: JP10.18, JP14.13
A4/18/SDA2: JP19.18, JP23.13
A4/18/SDA3: JP28.18, JP32.13
A4/18/SDA4: JP37.18, JP41.13
A4/18/SDA5: JP46.18, JP50.13
A4/18/SDA6: JP55.18, JP59.13
A4/18/SDA7: JP64.18, JP68.13
A5: JP28.A10, JP32.7
A5/19/SCL0: JP1.19, JP7.12
A5/19/SCL1: JP10.19, JP14.12
A5/19/SCL2: JP19.19, JP23.12
A5/19/SCL3: JP28.19, JP32.12
A5/19/SCL4: JP37.19, JP41.12
A5/19/SCL5: JP46.19, JP50.12
A5/19/SCL6: JP55.19, JP59.12
A5/19/SCL7: JP64.19, JP68.12
A6: JP28.A11, JP32.6
A6/1: JP10.20, JP14.11, SJ6.1
A6/2: JP19.20, JP23.11, SJ10.1
A6/3: JP28.20, JP32.11, SJ14.1
A6/4: JP37.20, JP41.11, SJ18.1
A6/5: JP46.20, JP50.11, SJ22.1
A6/6: JP55.20, JP59.11, SJ26.1
A6/7: JP64.20, JP68.11, SJ30.1
A6/20: JP1.20, JP7.11, SJ3.1
A7: JP37.A10, JP41.7
A7/1: JP10.21, JP14.10, SJ2.1
A7/2: JP19.21, JP23.10, SJ9.1
A7/3: JP28.21, JP32.10, SJ13.1
A7/4: JP37.21, JP41.10, SJ17.1
A7/5: JP46.21, JP50.10, SJ21.1
A7/6: JP55.21, JP59.10, SJ25.1
A7/7: JP64.21, JP68.10, SJ29.1
A7/21: JP1.21, JP7.10, SJ1.1
A8: JP37.A11, JP41.6
A8/1: JP10.22, JP14.9
A8/2: JP19.22, JP23.9
A8/3: JP28.22, JP32.9
A8/4: JP37.22, JP41.9
A8/5: JP46.22, JP50.9
A8/6: JP55.22, JP59.9
A8/7: JP64.22, JP68.9
A8/22: JP1.22, JP7.9
A9: JP46.A10, JP50.7
A9/1: JP10.23, JP14.8
A9/2: JP19.23, JP23.8
A9/3: JP28.23, JP32.8
A9/4: JP37.23, JP41.8
A9/5: JP46.23, JP50.8
A9/6: JP55.23, JP59.8
A9/7: JP64.23, JP68.8
A9/23: JP1.23, JP7.8
A10: JP1.A10, JP7.7
A11: JP1.A11, JP7.6
A12: JP46.A11, JP50.6
A13: JP55.A10, JP59.7
A14: JP55.A11, JP59.6
A14/DAC: JP1.A14/DAC, JP5.5
A14/DAC1: JP10.A14/DAC, JP12.5
A14/DAC2: JP19.A14/DAC, JP21.5
A14/DAC3: JP28.A14/DAC, JP30.5
A14/DAC4: JP37.A14/DAC, JP39.5
A14/DAC5: JP46.A14/DAC, JP48.5
A14/DAC6: JP55.A14/DAC, JP57.5
A14/DAC7: JP64.A14/DAC, JP66.5
A15: JP64.A10, JP68.7
A16: JP64.A11, JP68.6
AREF: JP1.AREF, JP7.5
AREF1: JP10.AREF, JP14.5
AREF2: JP19.AREF, JP23.5
AREF3: JP28.AREF, JP32.5
AREF4: JP37.AREF, JP41.5
AREF5: JP46.AREF, JP50.5
AREF6: JP55.AREF, JP59.5
AREF7: JP64.AREF, JP68.5
CTS: JP3.2, JP9.12
CTS1: JP16.2, JP17.12
CTS2: JP25.2, JP26.12
CTS3: JP34.2, JP35.12
CTS4: JP43.2, JP44.12
CTS5: JP52.2, JP53.12
CTS6: JP61.2, JP62.12
CTS7: JP70.2, JP71.12
DIO0: JP3.10, JP9.20
DIO1: JP3.9, JP9.19
DIO2: JP3.8, JP9.18
DIO3: JP3.7, JP9.17
DIO4: JP3.1, JP9.11
DIO5: JP3.5, JP9.15, R2.2
DIO6: JP16.1, JP17.11
DIO7: JP16.3, JP17.13
DIO8: JP16.7, JP17.17
DIO9: JP3.3, JP9.13
DIO10: JP16.8, JP17.18
DIO11: JP2.4, JP9.7
DIO12: JP2.7, JP9.4
DIO13: JP16.9, JP17.19
DIO14: JP16.10, JP17.20
DIO15: JP15.4, JP17.7
DIO16: JP15.7, JP17.4
DIO17: JP16.5, JP17.15, R7.2
DIO18: JP25.1, JP26.11
DIO19: JP25.3, JP26.13
DIO20: JP25.7, JP26.17
DIO21: JP25.8, JP26.18
DIO22: JP25.9, JP26.19
DIO23: JP25.10, JP26.20
DIO24: JP24.4, JP26.7
DIO25: JP24.7, JP26.4
DIO26: JP25.5, JP26.15, R13.2
DIO27: JP34.1, JP35.11
DIO28: JP34.3, JP35.13
DIO29: JP34.7, JP35.17
DIO30: JP34.8, JP35.18
DIO31: JP34.9, JP35.19
DIO32: JP34.10, JP35.20
DIO33: JP33.4, JP35.7
DIO34: JP33.7, JP35.4
DIO35: JP34.5, JP35.15, R18.2
DIO36: JP43.1, JP44.11
DIO37: JP43.3, JP44.13
DIO38: JP43.7, JP44.17
DIO39: JP43.8, JP44.18
DIO40: JP43.9, JP44.19
DIO41: JP43.10, JP44.20
DIO42: JP42.4, JP44.7
DIO43: JP42.7, JP44.4
DIO44: JP43.5, JP44.15, R23.2
DIO45: JP52.1, JP53.11
DIO46: JP52.3, JP53.13
DIO47: JP52.7, JP53.17
DIO48: JP52.8, JP53.18
DIO49: JP52.9, JP53.19
DIO50: JP52.10, JP53.20
DIO51: JP51.4, JP53.7
DIO52: JP51.7, JP53.4
DIO53: JP52.5, JP53.15, R28.2
DIO54: JP61.1, JP62.11
DIO55: JP61.3, JP62.13
DIO56: JP61.7, JP62.17
DIO57: JP61.8, JP62.18
DIO58: JP61.9, JP62.19
DIO59: JP61.10, JP62.20
DIO60: JP60.4, JP62.7
DIO61: JP60.7, JP62.4
DIO62: JP61.5, JP62.15, R33.2
DIO63: JP70.1, JP71.11
DIO64: JP70.3, JP71.13
DIO65: JP70.7, JP71.17
DIO66: JP70.8, JP71.18
DIO67: JP70.9, JP71.19
DIO68: JP70.10, JP71.20
DIO69: JP69.4, JP71.7
DIO70: JP69.7, JP71.4
DIO71: JP70.5, JP71.15, R38.2
DTR: JP2.2, JP9.9
DTR1: JP15.2, JP17.9
DTR2: JP24.2, JP26.9
DTR3: JP33.2, JP35.9
DTR4: JP42.2, JP44.9
DTR5: JP51.2, JP53.9
DTR6: JP60.2, JP62.9
DTR7: JP69.2, JP71.9
EXT_3.3V: JP8.1, SJ4.1, SJ5.2
EXT_3.3V1: JP18.1, SJ7.1, SJ8.2
EXT_3.3V2: JP27.1, SJ11.1, SJ12.2
EXT_3.3V3: JP36.1, SJ15.1, SJ16.2
EXT_3.3V4: JP45.1, SJ19.1, SJ20.2
EXT_3.3V5: JP54.1, SJ23.1, SJ24.2
EXT_3.3V6: JP63.1, SJ27.1, SJ28.2
EXT_3.3V7: JP72.1, SJ31.1, SJ32.2
GND: JP1.AGND, JP1.GND, JP1.GND1, JP2.1, JP4.1, JP5.3, JP6.1, JP6.2, JP6.3, JP7.3, JP8.2, JP9.10, LED1.C, LED4.C, LED5.C, S3.3
GND1: JP10.AGND, JP10.GND, JP10.GND1, JP11.1, JP12.3, JP13.1, JP13.2, JP13.3, JP14.3, JP15.1, JP17.10, JP18.2, LED6.C, LED9.C, LED10.C, S1.3
GND2: JP19.AGND, JP19.GND, JP19.GND1, JP20.1, JP21.3, JP22.1, JP22.2, JP22.3, JP23.3, JP24.1, JP26.10, JP27.2, LED11.C, LED14.C, LED15.C, S5.3
GND3: JP28.AGND, JP28.GND, JP28.GND1, JP29.1, JP30.3, JP31.1, JP31.2, JP31.3, JP32.3, JP33.1, JP35.10, JP36.2, LED16.C, LED19.C, LED20.C, S7.3
GND4: JP37.AGND, JP37.GND, JP37.GND1, JP38.1, JP39.3, JP40.1, JP40.2, JP40.3, JP41.3, JP42.1, JP44.10, JP45.2, LED21.C, LED24.C, LED25.C, S9.3
GND5: JP46.AGND, JP46.GND, JP46.GND1, JP47.1, JP48.3, JP49.1, JP49.2, JP49.3, JP50.3, JP51.1, JP53.10, JP54.2, LED26.C, LED29.C, LED30.C, S11.3
GND6: JP55.AGND, JP55.GND, JP55.GND1, JP56.1, JP57.3, JP58.1, JP58.2, JP58.3, JP59.3, JP60.1, JP62.10, JP63.2, LED31.C, LED34.C, LED35.C, S13.3
GND7: JP64.AGND, JP64.GND, JP64.GND1, JP65.1, JP66.3, JP67.1, JP67.2, JP67.3, JP68.3, JP69.1, JP71.10, JP72.2, LED36.C, LED39.C, LED40.C, S15.3
IN: JP2.8, JP9.3, LED3.C, S2.5
IN1: JP15.8, JP17.3, LED8.C, S4.5
IN2: JP24.8, JP26.3, LED13.C, S6.5
IN3: JP33.8, JP35.3, LED18.C, S8.5
IN4: JP42.8, JP44.3, LED23.C, S10.5
IN5: JP51.8, JP53.3, LED28.C, S12.5
IN6: JP60.8, JP62.3, LED33.C, S14.5
IN7: JP69.8, JP71.3, LED38.C, S16.5
unnamed: S4.6, SJ2.2
unnamed: S4.3, SJ6.2
unnamed: LED6.A, R6.1
unnamed: LED7.A, R5.2
unnamed: LED8.A, R8.2
unnamed: LED9.A, R9.1
unnamed: LED10.A, R7.1
unnamed: S6.6, SJ9.2
unnamed: S6.3, SJ10.2
unnamed: LED11.A, R12.1
unnamed: LED12.A, R10.2
unnamed: LED1.A, R11.1
unnamed: LED13.A, R14.2
unnamed: LED14.A, R15.1
unnamed: LED15.A, R13.1
unnamed: S8.6, SJ13.2
unnamed: LED2.A, R1.2
unnamed: S8.3, SJ14.2
unnamed: LED3.A, R3.2
unnamed: LED16.A, R17.1
unnamed: LED17.A, R16.2
unnamed: LED18.A, R19.2
unnamed: LED19.A, R20.1
unnamed: LED20.A, R18.1
unnamed: S10.6, SJ17.2
unnamed: S10.3, SJ18.2
unnamed: LED21.A, R22.1
unnamed: LED22.A, R21.2
unnamed: LED23.A, R24.2
unnamed: LED24.A, R25.1
unnamed: LED25.A, R23.1
unnamed: S12.6, SJ21.2
unnamed: S12.3, SJ22.2
unnamed: LED26.A, R27.1
unnamed: LED27.A, R26.2
unnamed: LED28.A, R29.2
unnamed: LED29.A, R30.1
unnamed: LED30.A, R28.1
unnamed: S14.6, SJ25.2
unnamed: S14.3, SJ26.2
unnamed: LED31.A, R32.1
unnamed: LED32.A, R31.2
unnamed: LED4.A, R4.1
unnamed: LED33.A, R34.2
unnamed: LED34.A, R35.1
unnamed: LED35.A, R33.1
unnamed: S16.6, SJ29.2
unnamed: S16.3, SJ30.2
unnamed: LED36.A, R37.1
unnamed: LED37.A, R36.2
unnamed: LED38.A, R39.2
unnamed: LED39.A, R40.1
unnamed: LED40.A, R38.1
unnamed: LED5.A, R2.1
unnamed: S2.6, SJ1.2
unnamed: S2.3, SJ3.2
OUT: JP2.9, JP9.2, LED2.C, S2.2
OUT1: JP15.9, JP17.2, LED7.C, S4.2
OUT2: JP24.9, JP26.2, LED12.C, S6.2
OUT3: JP33.9, JP35.2, LED17.C, S8.2
OUT4: JP42.9, JP44.2, LED22.C, S10.2
OUT5: JP51.9, JP53.2, LED27.C, S12.2
OUT6: JP60.9, JP62.2, LED32.C, S14.2
OUT7: JP69.9, JP71.2, LED37.C, S16.2
PROG: JP1.PROG, JP5.4
PROG1: JP10.PROG, JP12.4
PROG2: JP19.PROG, JP21.4
PROG3: JP28.PROG, JP30.4
PROG4: JP37.PROG, JP39.4
PROG5: JP46.PROG, JP48.4
PROG6: JP55.PROG, JP57.4
PROG7: JP64.PROG, JP66.4
RES: JP2.3, JP9.8
RES1: JP16.4, JP17.14
RES2: JP3.4, JP9.14
RES3: JP15.3, JP17.8
RES4: JP25.4, JP26.14
RES5: JP24.3, JP26.8
RES6: JP34.4, JP35.14
RES7: JP33.3, JP35.8
RES8: JP43.4, JP44.14
RES9: JP42.3, JP44.8
RES10: JP52.4, JP53.14
RES11: JP51.3, JP53.8
RES12: JP61.4, JP62.14
RES13: JP60.3, JP62.8
RES14: JP70.4, JP71.14
RES15: JP69.3, JP71.8
RESET: JP2.6, JP9.5, S3.1
RESET1: JP15.6, JP17.5, S1.1
RESET2: JP24.6, JP26.5, S5.1
RESET3: JP33.6, JP35.5, S7.1
RESET4: JP42.6, JP44.5, S9.1
RESET5: JP51.6, JP53.5, S11.1
RESET6: JP60.6, JP62.5, S13.1
RESET7: JP69.6, JP71.5, S15.1
RSSI: JP2.5, JP9.6, R4.2
RSSI1: JP15.5, JP17.6, R9.2
RSSI2: JP24.5, JP26.6, R15.2
RSSI3: JP33.5, JP35.6, R20.2
RSSI4: JP42.5, JP44.6, R25.2
RSSI5: JP51.5, JP53.6, R30.2
RSSI6: JP60.5, JP62.6, R35.2
RSSI7: JP69.5, JP71.6, R40.2
RTS: JP3.6, JP9.16
RTS1: JP16.6, JP17.16
RTS2: JP25.6, JP26.16
RTS3: JP34.6, JP35.16
RTS4: JP43.6, JP44.16
RTS5: JP52.6, JP53.16
RTS6: JP61.6, JP62.16
RTS7: JP70.6, JP71.16
UART_RX: JP1.0, JP4.2, S2.1
UART_RX1: JP10.0, JP11.2, S4.1
UART_RX2: JP19.0, JP20.2, S6.1
UART_RX3: JP28.0, JP29.2, S8.1
UART_RX4: JP37.0, JP38.2, S10.1
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

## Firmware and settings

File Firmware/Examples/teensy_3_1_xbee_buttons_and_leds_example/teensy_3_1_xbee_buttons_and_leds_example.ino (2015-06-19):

#include <AltSoftSerial.h>
//To use this example you will need to have the following connections:
//  4 buttons connected to pins 14 through 17, normally open, short to ground.
//  8 LEDs connected to pins 4 through 11, each with their own current limiting resistor.
//  The sketch is intended to have leds with a common ground, though using a common power
//  will work invertedly.
//
//You will also need:
//  A Teensy 3.1 to XBee adapter board with XBee
//  A 2nd XBee connected to serial terminal (USB dongle with Tera Term for example)
//  The S-UART / UART1 switch set to S-UART for a software UART using the altSoftSerial library
//  
//Load the sketch and press the buttons.  In the serial terminal the '0's change to '1's.
//Press 1-8 on the keyboard in the terminal window.  The LEDs will illuminate.  Press enter or
//any other key to clear the LEDs.

//Marshall @ SparkFun Electronics, 2015.
  
  
// Define pin locations
int upleftButton = 14;
int uprightButton = 15;
int downleftButton = 16;
int downrightButton = 17;
int led1Pin = 4;
int led2Pin = 5;
int led3Pin = 6;
int led4Pin = 7;
int led5Pin = 8;
int led6Pin = 9;
int led7Pin = 10;
int led8Pin = 11;

AltSoftSerial altSerial;



void setup() {
  // initialize serial communication at 9600 bits per second:
  Serial.begin(9600);
  altSerial.begin(9600);

  // Setup the pin directions
  pinMode(upleftButton, INPUT_PULLUP);
  pinMode(uprightButton, INPUT_PULLUP);
  pinMode(downleftButton, INPUT_PULLUP);
  pinMode(downrightButton, INPUT_PULLUP);
  pinMode(led1Pin, OUTPUT);
  pinMode(led2Pin, OUTPUT);
  pinMode(led3Pin, OUTPUT);
  pinMode(led4Pin, OUTPUT);
  pinMode(led5Pin, OUTPUT);
  pinMode(led6Pin, OUTPUT);
  pinMode(led7Pin, OUTPUT);
  pinMode(led8Pin, OUTPUT);

}

// the loop routine runs over and over again forever:
void loop() {
  //*******************************************************************//
  // Transmitting.  This section reads button states and builds a packet
  // that is shipped over the airwaves.  The basic packet has a start
  // char of ~, 9 user bytes, and terminates with a carriage return
  // "~000000000\r"
  
  int buttonState;

  //Write the tilde to the XBee.  This signifies start of packet
  altSerial.write('~');

  // read the input pin:
  buttonState = digitalRead(upleftButton);
  Serial.print("up left is ");
  // print out the state of the button to the serial monitor:
  Serial.println(buttonState);
  buttonState ^= 0x01;
  // write the value to the XBee packet
  altSerial.print(buttonState);

  // read the input pin:
  buttonState = digitalRead(uprightButton);
  // print out the state of the button to the serial monitor:
  Serial.print("up right is ");
  Serial.println(buttonState);
  buttonState ^= 0x01;
  // write the value to the XBee packet
  altSerial.print(buttonState);

  // read the input pin:
  buttonState = digitalRead(downleftButton);
  // print out the state of the button to the serial monitor:
  Serial.print("down left is ");
  Serial.println(buttonState);
  buttonState ^= 0x01;
  // write the value to the XBee packet
  altSerial.print(buttonState);

  // read the input pin:
  buttonState = digitalRead(downrightButton);
  // print out the state of the button to the serial monitor:
  Serial.print("down right is ");
  Serial.println(buttonState);
  buttonState ^= 0x01;
  // write the value to the XBee packet
  altSerial.print(buttonState);

  // fill the rest of the packet with zeros
  altSerial.print('0');
  altSerial.print('0');
  altSerial.print('0');
  altSerial.print('0');
  altSerial.print('0');
  // Proved an end of line char for the interpreter to pick up on
  altSerial.write(0x0D);

  //*******************************************************************//
  // Receiving.  This section check for new serial data and turns on an
  // LED that corresponds to a number key entered.  All other characters
  // including return, LF, CR, etc. cause all LEDs to be turned off.
  if (altSerial.available())
  {
    char c;
    c = altSerial.read();
    switch(c)
    {
    case '1':
      digitalWrite(4, 1);
      break;
    case '2':
      digitalWrite(5, 1);
      break;
    case '3':
      digitalWrite(6, 1);
      break;
    case '4':
      digitalWrite(7, 1);
      break;
    case '5':
      digitalWrite(8, 1);
      break;
    case '6':
      digitalWrite(9, 1);
      break;
    case '7':
      digitalWrite(10, 1);
      break;
    case '8':
      digitalWrite(11, 1);
      break;
    default:
      //Clear all pins on other keys
      digitalWrite(4, 0);
      digitalWrite(5, 0);
      digitalWrite(6, 0);
      digitalWrite(7, 0);
      digitalWrite(8, 0);
      digitalWrite(9, 0);
      digitalWrite(10, 0);
      digitalWrite(11, 0);
      break;

    }

  }


  delay(100);        // delay in between reads for stability
}

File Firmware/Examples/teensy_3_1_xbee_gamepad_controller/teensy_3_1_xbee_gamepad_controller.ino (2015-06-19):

//This example is used to make an 8 button (NES like) remote game pad.  It tracks button-down
//and button-up information so that the games are playable.  Without tracking that stuff,
//your character would only have one level of jump.
//
//The other end of the link behaves like a USB keyboard and 'presses keys' for the emulator
//
//To use this example you will need to have the following connections:
//  4 buttons connected to pins 14 through 17, normally open, short to ground.
//  8 LEDs connected to pins 4 through 11, each with their own current limiting resistor
//  An Teensy 3.1 to XBee adapter board with XBee
//  An 2nd XBee connected to serial terminal (USB dongle with Tera Term for example)
//  The S-UART / UART1 switch set to S-UART for a software UART using the altSoftSerial library
//  
//  Load the sketch and press the buttons.  In the serial terminal the '0's change to '1's.
//  Press 1-8 on the keyboard in the terminal window.  The LEDs will illuminate.  Press enter or
//  any other key to clear the LEDs.

//Marshall@SparkFun Electronics, 2015


// Define pin locations
int led = 13;
int padLeftPin = 8;
int padRightPin = 9;
int padUpPin = 6;
int padDownPin = 7;
int btnStartPin = 2;
int btnSelectPin = 3;
int btnAPin = 5;
int btnBPin = 4;

  int newState = 1;
  int padLeftState = 1;
  int padRightState = 1;
  int padUpState = 1;
  int padDownState = 1;
  int btnStartState = 1;
  int btnSelectState = 1;
  int btnAState = 1;
  int btnBState = 1;
  int previousPadLeftState = 1;
  int previousPadRightState = 1;
  int previousPadUpState = 1;
  int previousPadDownState = 1;
  int previousBtnStartState = 1;
  int previousBtnSelectState = 1;
  int previousBtnAState = 1;
  int previousBtnBState = 1;
  
void setup() {
  // initialize serial communication at 9600 bits per second:
  Serial.begin(9600);
  Serial1.begin(9600);

  // Setup the pin directions
  pinMode(led, OUTPUT);     
  pinMode(padLeftPin, INPUT_PULLUP);
  pinMode(padRightPin, INPUT_PULLUP);
  pinMode(padUpPin, INPUT_PULLUP);
  pinMode(padDownPin, INPUT_PULLUP);
  pinMode(btnStartPin, INPUT_PULLUP);
  pinMode(btnSelectPin, INPUT_PULLUP);
  pinMode(btnAPin, INPUT_PULLUP);
  pinMode(btnBPin, INPUT_PULLUP);

}

// the loop routine runs over and over again forever:
void loop()
{
  //*******************************************************************//
  // Transmitting.  This section reads button states and builds a packet
  // that is shipped over the airwaves.  The basic packet has a start
  // char of ~, 9 user bytes, and terminates with a carriage return
  // "~000000000\r"

  //Get the states

  padLeftState = digitalRead(padLeftPin);
  if(previousPadLeftState != padLeftState)
  {
    previousPadLeftState = padLeftState;
    newState = 1;
  }
  padRightState = digitalRead(padRightPin);
  if(previousPadRightState != padRightState)
  {
    previousPadRightState = padRightState;
    newState = 1;
  }
  padUpState = digitalRead(padUpPin);
  if(previousPadUpState != padUpState)
  {
    previousPadUpState = padUpState;
    newState = 1;
  }
  padDownState = digitalRead(padDownPin);
  if(previousPadDownState != padDownState)
  {
    previousPadDownState = padDownState;
    newState = 1;
  }
  btnStartState = digitalRead(btnSelectPin);
  if(previousBtnStartState != btnStartState)
  {
    previousBtnStartState = btnStartState;
    newState = 1;
  }
  btnSelectState = digitalRead(btnStartPin);
  if(previousBtnSelectState != btnSelectState)
  {
    previousBtnSelectState = btnSelectState;
    newState = 1;
  }
  btnAState = digitalRead(btnAPin);
  if(previousBtnAState != btnAState)
  {
    previousBtnAState = btnAState;
    newState = 1;
  }
  btnBState = digitalRead(btnBPin);
  if(previousBtnBState != btnBState)
  {
    previousBtnBState = btnBState;
    newState = 1;
  }

  if( newState == 1 )
  {
    //Print the packet
    //Write the tilde to the XBee.  This signifies start of packet
    Serial1.write('~');

    Serial1.print(padLeftState);
    Serial1.print(padRightState);
    Serial1.print(padUpState);
    Serial1.print(padDownState);
    Serial1.print(btnStartState);
    Serial1.print(btnSelectState);
    Serial1.print(btnBState);
    Serial1.print(btnAState);

    // fill the rest of the packet with zeros
    Serial1.print('0');


    // Provide an end of line char for the interpreter to pick up on
    Serial1.write(0x0D);	 

    //Clear tne new state
    newState = 0; 
  }




  delay(10);        // delay in between reads for stability
}

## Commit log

2015-02-20 Initial Hardware Commit.
    [Teensy_3_1 XBee Adapter.brd, Teensy_3_1 XBee Adapter.sch, Teensy_3_1 XBee Adapter_TearDrops.brd]
2015-02-20 Fixed vector font
    [Teensy_3_1 XBee Adapter.brd, Teensy_3_1 XBee Adapter_TearDrops.brd]
2015-02-24 Opened the board up a bit
    [Teensy_3_1 XBee Adapter.brd, Teensy_3_1 XBee Adapter.sch]
2015-02-24 Removed teardrops example
    [Teensy_3_1 XBee Adapter_TearDrops.brd]
2015-02-26 Fixed silk. Preparing for first proto
    [Teensy_3_1 XBee Adapter.brd, Teensy_3_1 XBee Adapter.sch]
2015-02-26 Fliping bottom silk labels
    [Teensy_3_1 XBee Adapter.brd]
2015-02-27 Completed first round of QC notes
    [Teensy_3_1 XBee Adapter.brd, Teensy_3_1 XBee Adapter.sch]
2015-03-02 Fixed airwire, updated revision
    [Teensy_3_1 XBee Adapter.brd, Teensy_3_1 XBee Adapter.sch]
2015-03-19 SW examples for UART1 and SUART added
2015-03-20 Prototype tested and documented. Silkscreen was adjusted and two 0603 components were twisted so that they are in the same direction as the others.
    [XBee power test.ods]
2015-03-30 Final proto fixes
    [Teensy_3_1 XBee Adapter.brd]
2015-03-31 Serviced github issues and deployed gitignore file
    [Teensy_3_1 XBee Adapter.brd]
2015-04-02 Fixed A-B button swap
2015-04-15 removed micro fids, added regular 1x2
    [Teensy_3_1 XBee Adapter.brd, Teensy_3_1 XBee Adapter.sch]
2015-04-15 created panel v10
    [Teensy_3_1_XBee Adapter_Panel_v10.brd]
2015-06-05 Fixing documentation
    [XBee power test.ods]
2015-06-19 updating README, file structure for release
    [Teensy_3_1 XBee _Adapter.brd, Teensy_3_1 XBee _Adapter.sch, Teensy_3_1_XBee Adapter_Panel_v10.brd]
2020-06-01 Remove depreciated definitions and update functions
    It appears that the behavior of a function has been removed and `BYTE` is no longer a keyword in Arduino after a certain version => https://forum.arduino.cc/index.php?topic=85382.msg639273#msg639273 .
    Minor update so that the users can still send/receive characters.
    [teensy_3_1_xbee_SUART_example.ino, teensy_3_1_xbee_UART1_example.ino]

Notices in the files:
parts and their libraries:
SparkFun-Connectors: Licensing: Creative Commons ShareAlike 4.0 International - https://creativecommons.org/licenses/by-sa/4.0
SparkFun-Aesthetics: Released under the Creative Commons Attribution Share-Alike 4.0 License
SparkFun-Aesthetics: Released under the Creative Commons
